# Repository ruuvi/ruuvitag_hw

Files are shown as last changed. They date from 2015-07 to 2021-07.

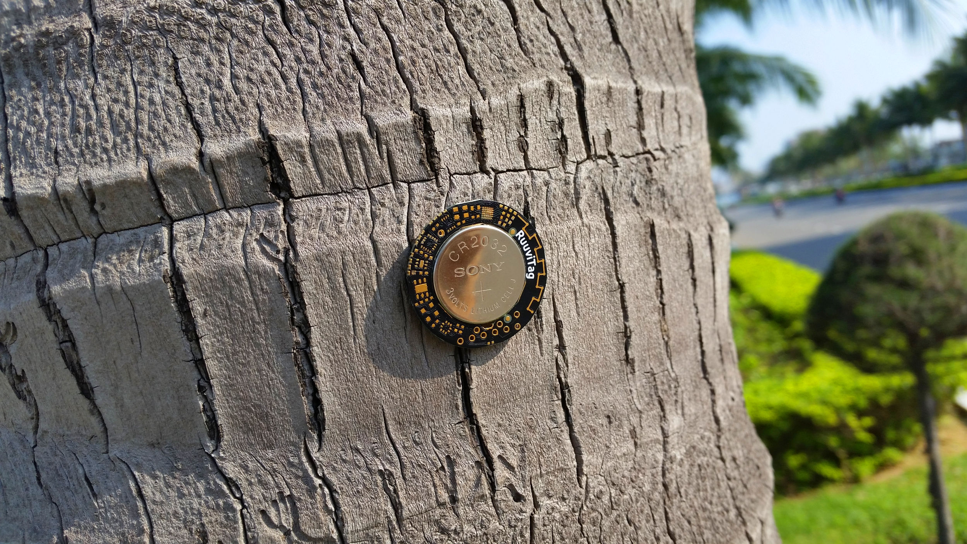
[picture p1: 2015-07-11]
ruuvitag_reva1/ruuvitag_reva1.jpg

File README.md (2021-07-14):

# RuuviTag: Open-Source Sensor Platform

* Rev.A1 - the first RuuviTag ever invented.
* Rev.A2 - minor modifications. Note: neither A1 or A2 are currently mass produced by Ruuvi.
* Rev.B1 - a completely new design. Larger footprint, nRF52 radio chip etc.
* Rev.B2 - an enhanced version of the B1.
* Rev.B3 - an enhanced version of the B2.
* Rev.B4 - an enhanced version of the B3.
* Rev.B5 - an enhanced version of the B4.
* Rev.B6 - an enhanced version of the B5.
* Rev.B7.1 - an enhanced version of the B6.
* Rev.B8 - an enhanced version of the B7.1.

All the design files are licensed using Attribution-ShareAlike 4.0 International (CC BY-SA 4.0).
Copyright: Lauri Jämsä, Ruuvi Innovations Ltd. Neither the name of the RuuviTag nor the names of its contributors may be used to endorse or promote products derived from this project without specific prior written permission. While unofficial products should not have "Ruuvi" in their name, it's okay to describe your product in relation to the Ruuvi projects. More info: license@ruuvi.com.

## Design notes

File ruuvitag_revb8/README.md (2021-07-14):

# RuuviTag Rev.B8

### Changelog after Rev.B7.1:

* Remove the reset button
* Remove the reverse polarity protection FET
* Make all the vias smaller
* Add a TMP117
* Replace the BME280 with a DPS310
* Add external I2C pull-ups
* Power sensors using GPIO pins
* 100nF caps to 1uF (except the nRF’s DEC cap)
* Add a 47uF cap
* Connect P0.26 to GND to supress radio emissions

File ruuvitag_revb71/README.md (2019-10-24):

# RuuviTag Rev.B7.1

### Changelog after Rev.B6:

* Add NFC series inductors L4 and L5
* Add a second BME280 bypass cap C15
* Modify battery clip's footprint to support also SMD parts
* Enhance button footprints
* Add two new alignment holes and a PCB edge alignment slot
* Modify battery holder's PCB shape
* Several minor layout modifications
* Add an optional SHTC3

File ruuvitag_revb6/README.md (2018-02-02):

# RuuviTag Rev.B6

### Changelog after Rev.B5:

* Replace the 10-pin 0.05" pitch ARM debug connector by TagConnect and connect its pin #1 to +BATT instead of VDD.
* Make buttons’ pads larger

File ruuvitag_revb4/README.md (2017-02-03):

# RuuviTag Rev.B4

### Changelog after Rev.B3:

* Remove SPI_MOSI and VDD traces from under BME280
* Alignment holes 1mm -> 1.2mm
* Bottom solder mask cutout under the nRF52 to avoid risk of mask pocket
* Add R and B silkscreen markings
* Two new test points: P24 and P25. Connected to P0.31 and P0.30.
* Many minor modifications to routing

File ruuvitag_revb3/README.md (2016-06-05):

# RuuviTag Rev.B3

### Changelog after Rev.B2:

#### Schema

* Accelerometer from LIS3 (3x3mm) series to LIS2 (2x2mm) series. Default component: LIS2DH12
* Add INT2 line (accelerometer). Connected to P0.06

#### Layout

* Make battery holder mechanism stronger (1mm -> 1.2mm) and tighter (~50um)
* Move P10 test point to new location
* Move P11 test point to 0.5mm lower position
* New buttons

#### Accelerometer otions (TBD)

* LIS2DH12: 12bit, 2-16g, 1Hz-5.3kHz, 32 level FIFO, 1000pcs 0.638EUR (Mouser)
* LIS2DE12: 8bit, 2-16g, 1Hz-5.3kHz, 32 level FIFO, 0.616EUR (Mouser)
* IIS2DH: 12bit, 2-16g, 1Hz-5.3kHz, 32 level FIFO, 1000pcs 1.45EUR (Mouser)
* MIS2DH: 2.16g, 1Hz-5.3kHz, no FIFO

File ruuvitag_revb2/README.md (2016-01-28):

# RuuviTag Rev.B2

Changelog after Rev.B1:

* Remove useless pull-up resistor from BUTTON1 (nRF52 has internal ones)
* Name LED3 to LED2
* Mark C12 (connected to DEC2 pin) to not assembled
* Remove SPI DataFlash
* Remove 0ohm series resistor from antenna output
* Remove PI antenna matching network (leave the shunt)
* 32MHz crystal from 3225 to 2016 size
* Completely redesigned battery holder mechanism
* LEDs from 0402 to 0603 (more low forward voltage choices available in 0603 size)
* Add a NFC antenna 
* Fix accelerometer's footprint (LGA-16) according STM's TN0018 application note. ADXL363 not supported any more (but probably reflows correctly anyways)
* SPI_ACC_CS from P0.11 to P0.08
* Remove test pads from P0.26 and P0.27
* Add test pads to P0.04, P0.05, P0.13, P0.17, P0.19, P0.25, P0.28, P0.29, GND, GND, VDD, Bat+, SWO, SWDIO, SWDCLK and RESET
* Update BOM's critical components according Nordic's reference design

Accelerometer options:

* H3LIS100DL: 8bit, 100g, 400Hz
* H3LIS200DL: 8bit, 100-200g, 1kHz
* H3LIS331DL: 12bit, 100-400g, 1kHz
* LIS331DLH: 2-8g, 1uA sleep, 10uA 10Hz, 250uA 1kHz max datarate, 1000pcs 1EUR (Mouser)
* LIS331HH: 12bit, 6-24g, 1uA sleep, 10uA 10Hz, 250uA 1kHz max datarate, 1000pcs 2.4EUR (Mouser)
* LIS3DSH: 16bit, 2-16g, 2uA sleep, 11uA 3Hz, 225uA 1.6kHz max datarate, 1000pcs 1.3EUR (Mouser)
* LIS3DH: 16bit, 2-16g, 0.5uA sleep, 2uA 1Hz, 11uA 50Hz, 5kHz max datarate, 1000pcs 0.96EUR (Mouser)
* LIS3DE: 8bit, 2-16g, 0.5uA sleep, 2uA 1Hz, 11uA 50Hz, 5kHz max datarate, 1000pcs 0.6EUR (Mouser, not yet in stock)

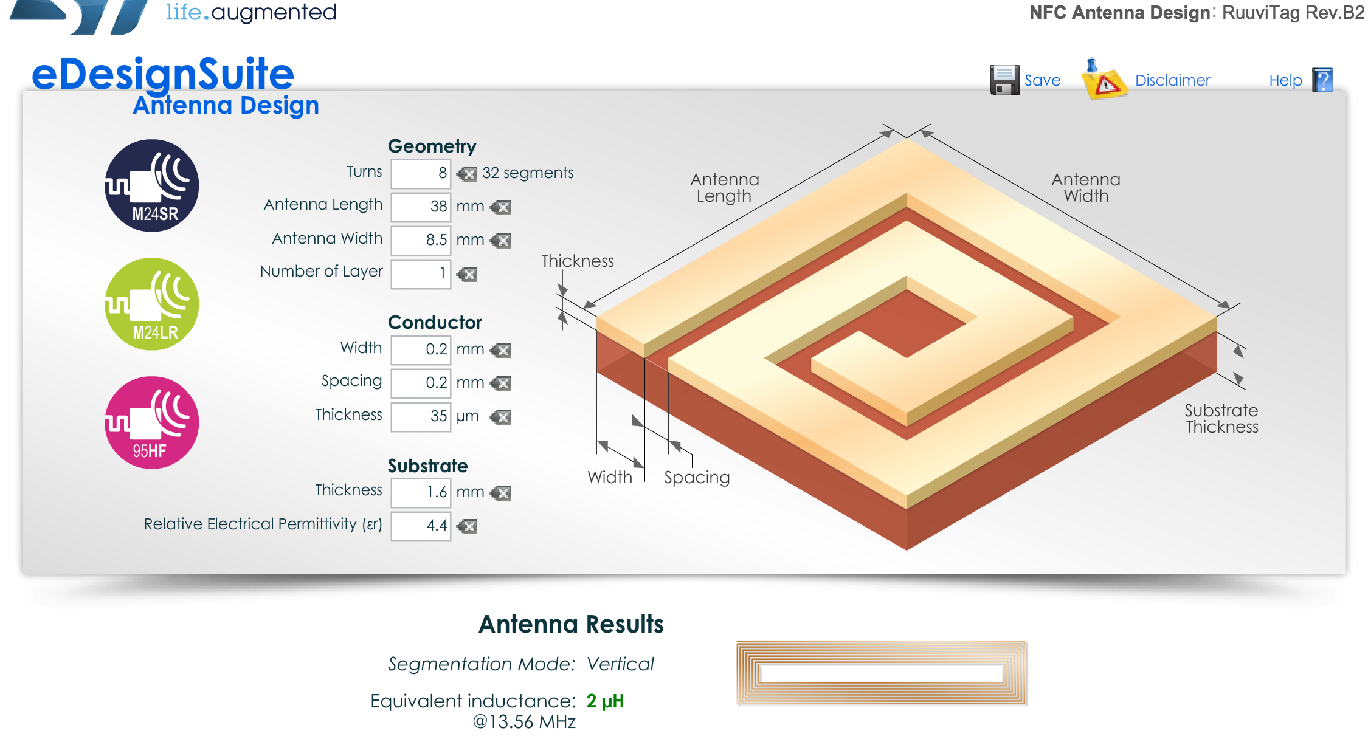
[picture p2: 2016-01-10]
ruuvitag_revb2/nfc-antenna/antenna-specs.png

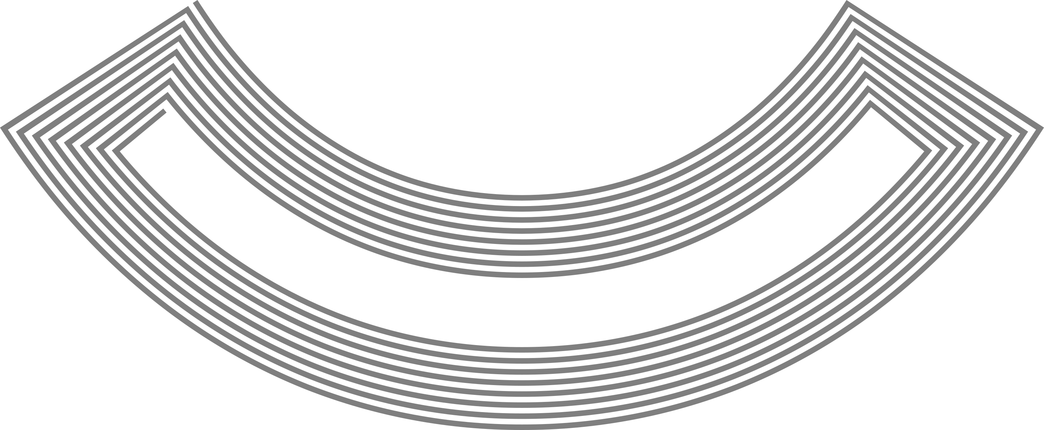
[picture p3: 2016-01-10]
ruuvitag_revb2/nfc-antenna/inkscape_export_2000dpi.png

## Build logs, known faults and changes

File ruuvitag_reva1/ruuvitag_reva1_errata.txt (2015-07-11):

Known HW limitations:

1) 16MHz crystal pinout is wrooong.

FIX: Turn crystal oscillator 90 degrees to left (or right).

2) Mysterious behaviour of reset pin. Not proven to happen too often, probably not an issue. DA14580 should have an internal pull-down resistor.

FIX: Nope.

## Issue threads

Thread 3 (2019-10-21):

Tagconnect orientation differs between revb6 files and actual PCB

PetteriAimonen, 2019-10-21:
First of all, thanks for the great product! I'll just point out this minor difference that I noticed.

The revb6 files from this repository look like this, with a single tagconnect hole towards the edge:
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

But the PCB looks like this, with two tagconnect holes towards the edge:
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

The reason I noticed this is because I designed a small add-on pcb that solders onto the testpads:
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

laurijamsa, 2019-10-24:
Orientation of the connector has changed after B6. See the latest B7.1 project design files for more info.

Closed 2019-10-24.

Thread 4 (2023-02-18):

KiCad v7/v6 "rescue symbols" error opening schematic (b8)

SensorPlay, 2023-02-18:
Opening the project file > schematic generates "rescue symbols" error (screencap)

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

I thought this may be a new version error, so I rolled back to 5.1.8 KiCad (the version on the schematic pdf), but same errors are generated.

I'm not a super experienced KiCad user (Altium), but usually with library errors there's a library file that needs to be imported?

Cool project btw.

laurijamsa, 2023-02-19:
These aren't actually errors but the app just notifies you that some old symbols may break the schematic when opened. I just tried to open the same project using KiCad 7 and it opened just fine. Download this schematic component library and place it in same folder with the ruuvitag_hw folder and then relative library paths of the project should work correctly: https://github.com/ruuvi/kicad-library

Closed 2023-02-19.

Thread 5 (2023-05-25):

What kind/model of antenna do you use to achieve long range?

Michaelszeng, 2023-05-25:
The schematics don't seem to specify.

laurijamsa, 2023-05-26:
It is a custom PCB antenna. You can open the electronics project using KiCad.

Closed 2023-05-26.

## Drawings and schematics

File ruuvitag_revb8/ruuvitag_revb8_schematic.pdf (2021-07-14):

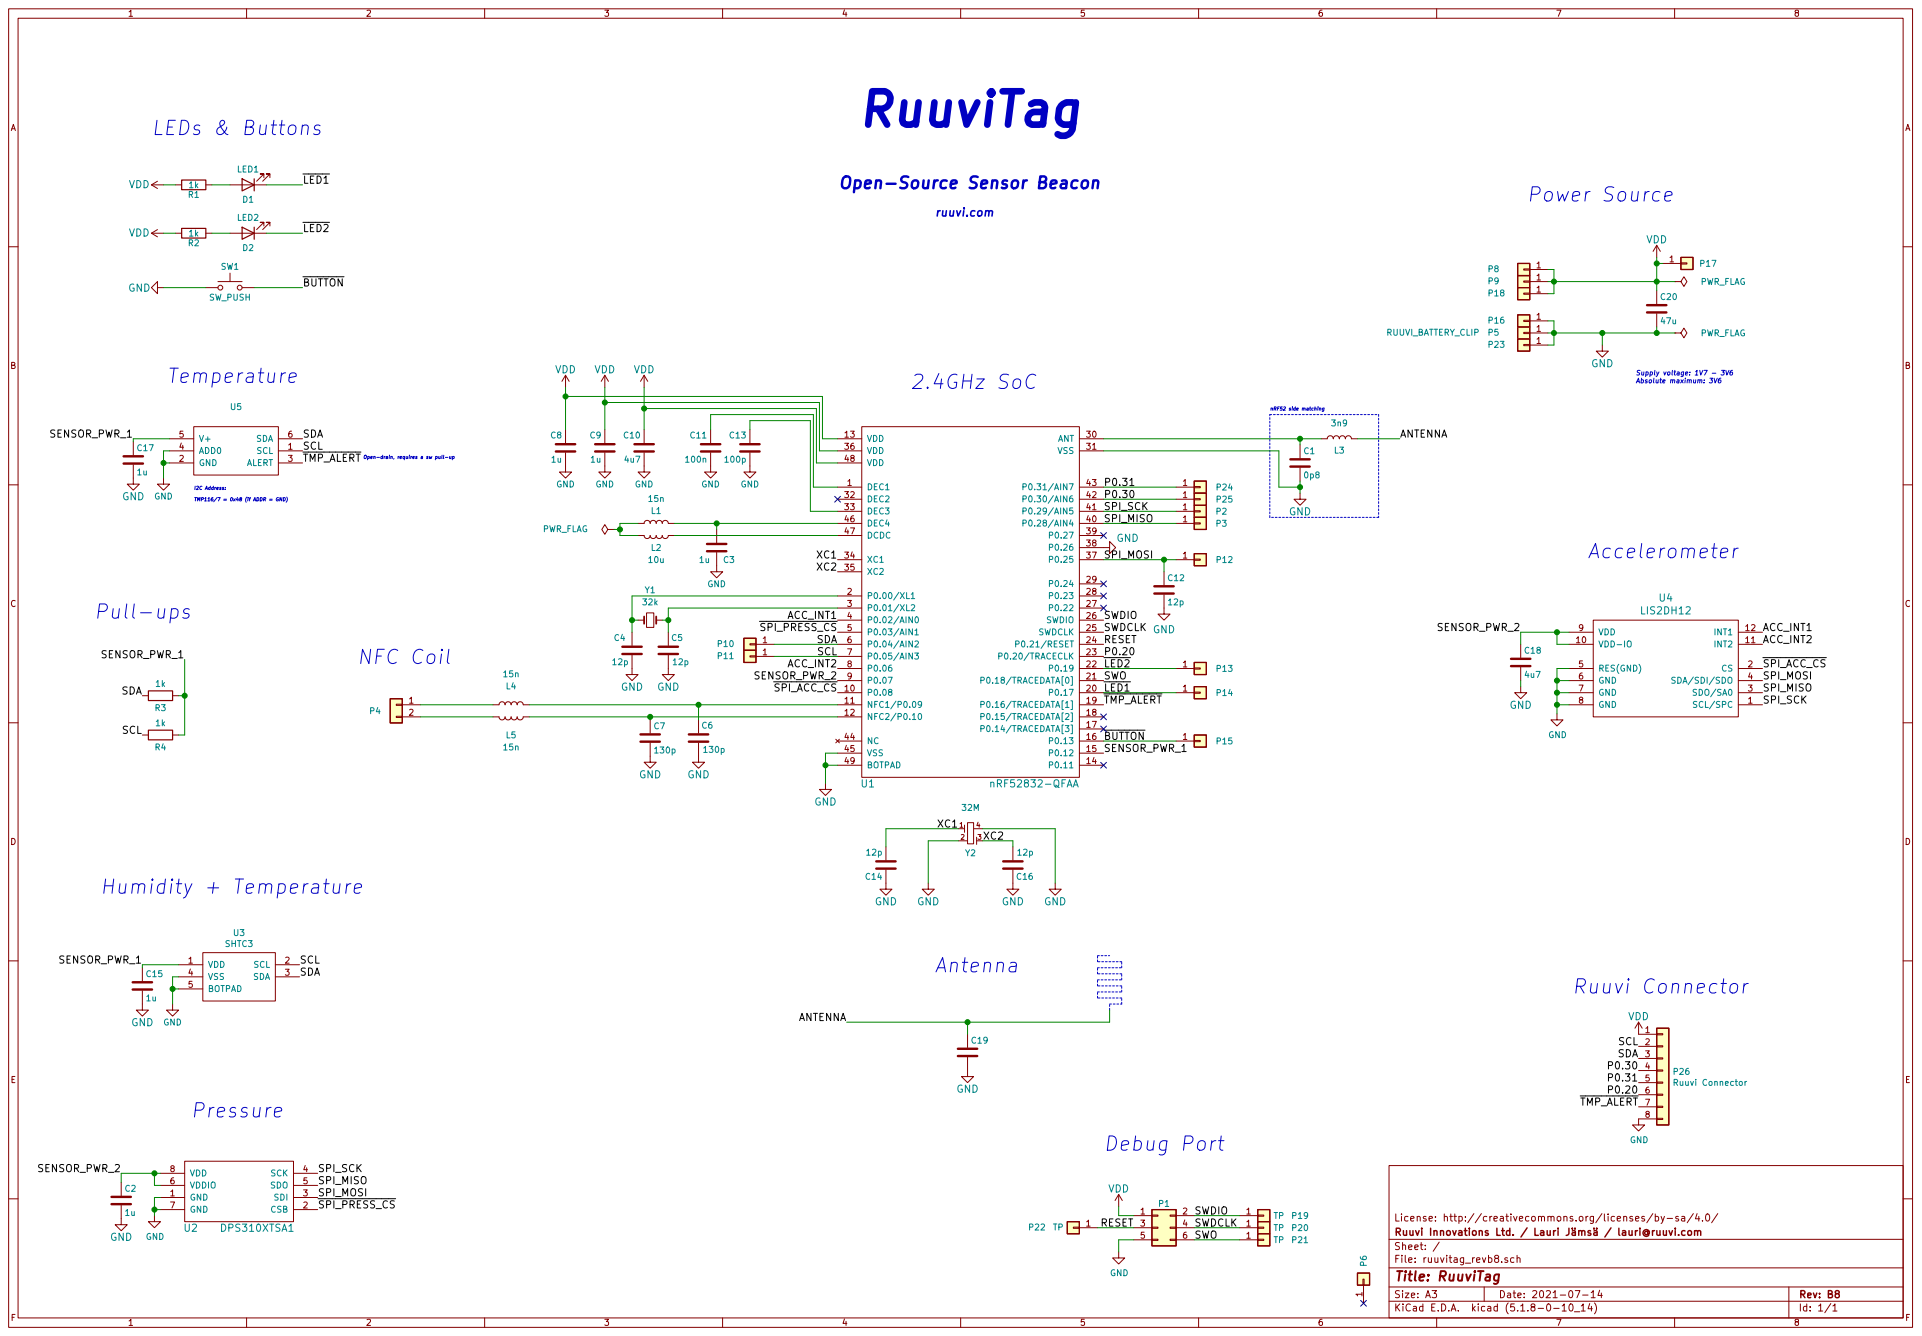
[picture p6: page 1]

nRF52 side matching Open-drain, requires a sw pull-up LEDs & Buttons

Open-Source Sensor Beacon

Supply voltage: 1V7 - 3V6 Absolute maximum: 3V6 Pull-ups

SPI_PRESS_CS

SCL

License: http://creativecommons.org/licenses/by-sa/4.0/
File: ruuvitag_revb8.sch Sheet: / Ruuvi Innovations Ltd. / Lauri Jämsä / lauri@ruuvi.com

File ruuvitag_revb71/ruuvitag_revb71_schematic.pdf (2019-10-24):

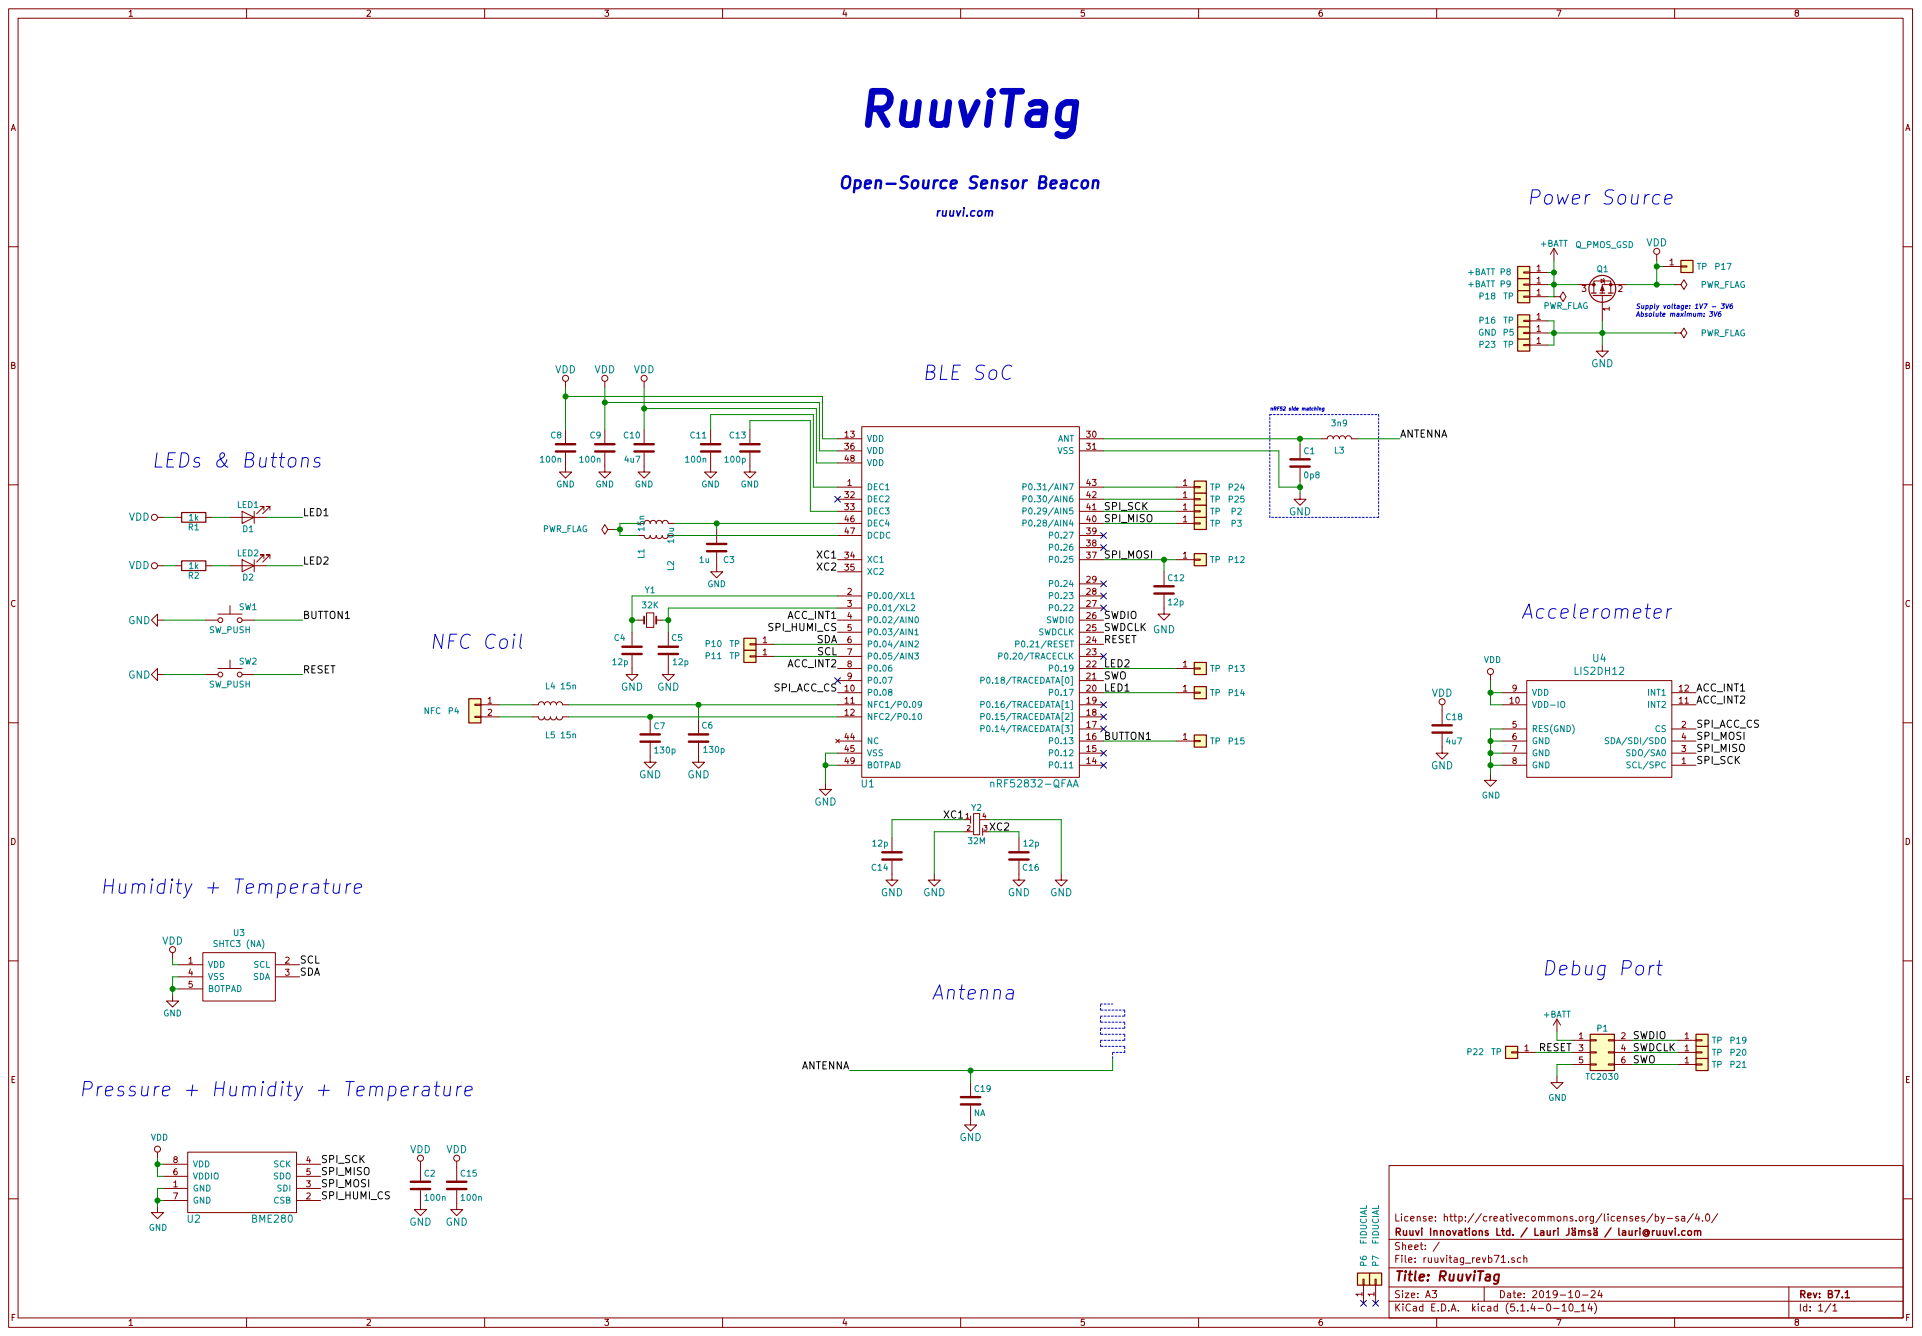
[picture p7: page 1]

Power Source Open-Source Sensor Beacon

Supply voltage: 1V7 - 3V6 Absolute maximum: 3V6 Pressure + Humidity + Temperature

nRF52 side matching NFC Coil

SPI_HUMI_CS | ACC_INT1

SCL

1 P7 FIDUCIAL
License: http://creativecommons.org/licenses/by-sa/4.0/
File: ruuvitag_revb71.sch Sheet: / Ruuvi Innovations Ltd. / Lauri Jämsä / lauri@ruuvi.com

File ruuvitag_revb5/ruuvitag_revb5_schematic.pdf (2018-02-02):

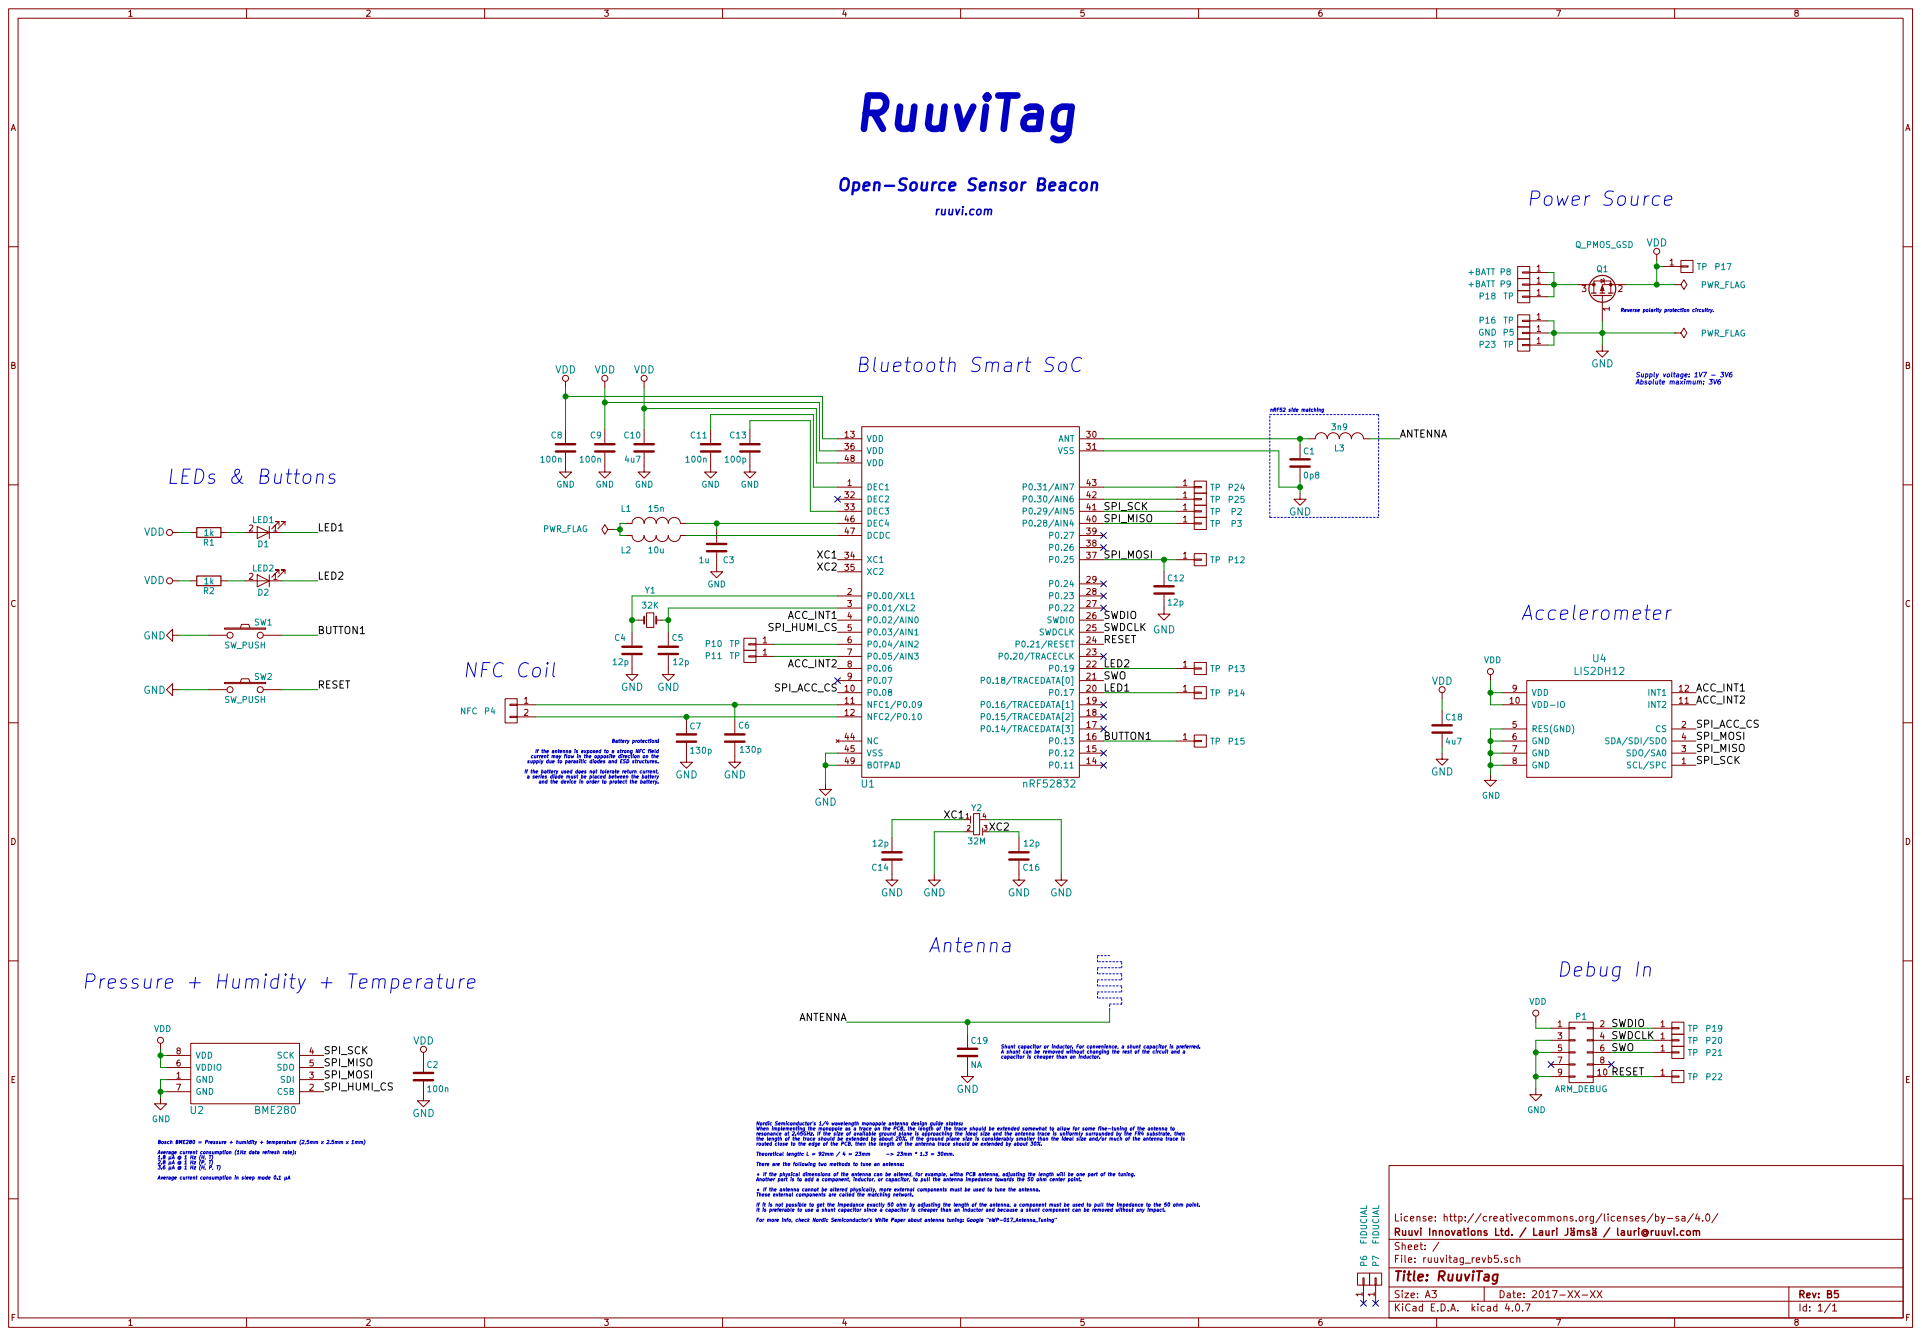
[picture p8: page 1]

Open-Source Sensor Beacon

Supply voltage: 1V7 - 3V6 Absolute maximum: 3V6 1 +BATT P8 LED2

Reverse polarity protection circuitry.

If the antenna is exposed to a strong NFC field
current may flow in the opposite direction on the
supply due to parasitic diodes and ESD structures.

Shunt capacitor or inductor. For convenience, a shunt capacitor is preferred. A shunt can be removed without changing the rest of the circuit and a
capacitor is cheaper than an inductor.

Nordic Semiconductor's 1/4 wavelength monopole antenna design guide states: When implementing the monopole as a trace on the PCB, the length of the trace should be extended somewhat to allow for some fine-tuning of the antenna to
resonance at 2.45GHz. If the size of available ground plane is approaching the ideal size and the antenna trace is uniformly surrounded by the FR4 substrate, then
the length of the trace should be extended by about 20%. If the ground plane size is considerably smaller than the ideal size and/or much of the antenna trace is

If the physical dimensions of the antenna can be altered, for example, witha PCB antenna, adjusting the length will be one part of the tuning. Another part is to add a component, inductor, or capacitor, to pull the antenna impedance towards the 50 ohm center point.

If the antenna cannot be altered physically, more external components must be used to tune the antenna. These external components are called the matching network.

If it is not possible to get the impedance exactly 50 ohm by adjusting the length of the antenna, a component must be used to pull the impedance to the 50 ohm point.

1 P7 FIDUCIAL
License: http://creativecommons.org/licenses/by-sa/4.0/
File: ruuvitag_revb5.sch Sheet: / Ruuvi Innovations Ltd. / Lauri Jämsä / lauri@ruuvi.com

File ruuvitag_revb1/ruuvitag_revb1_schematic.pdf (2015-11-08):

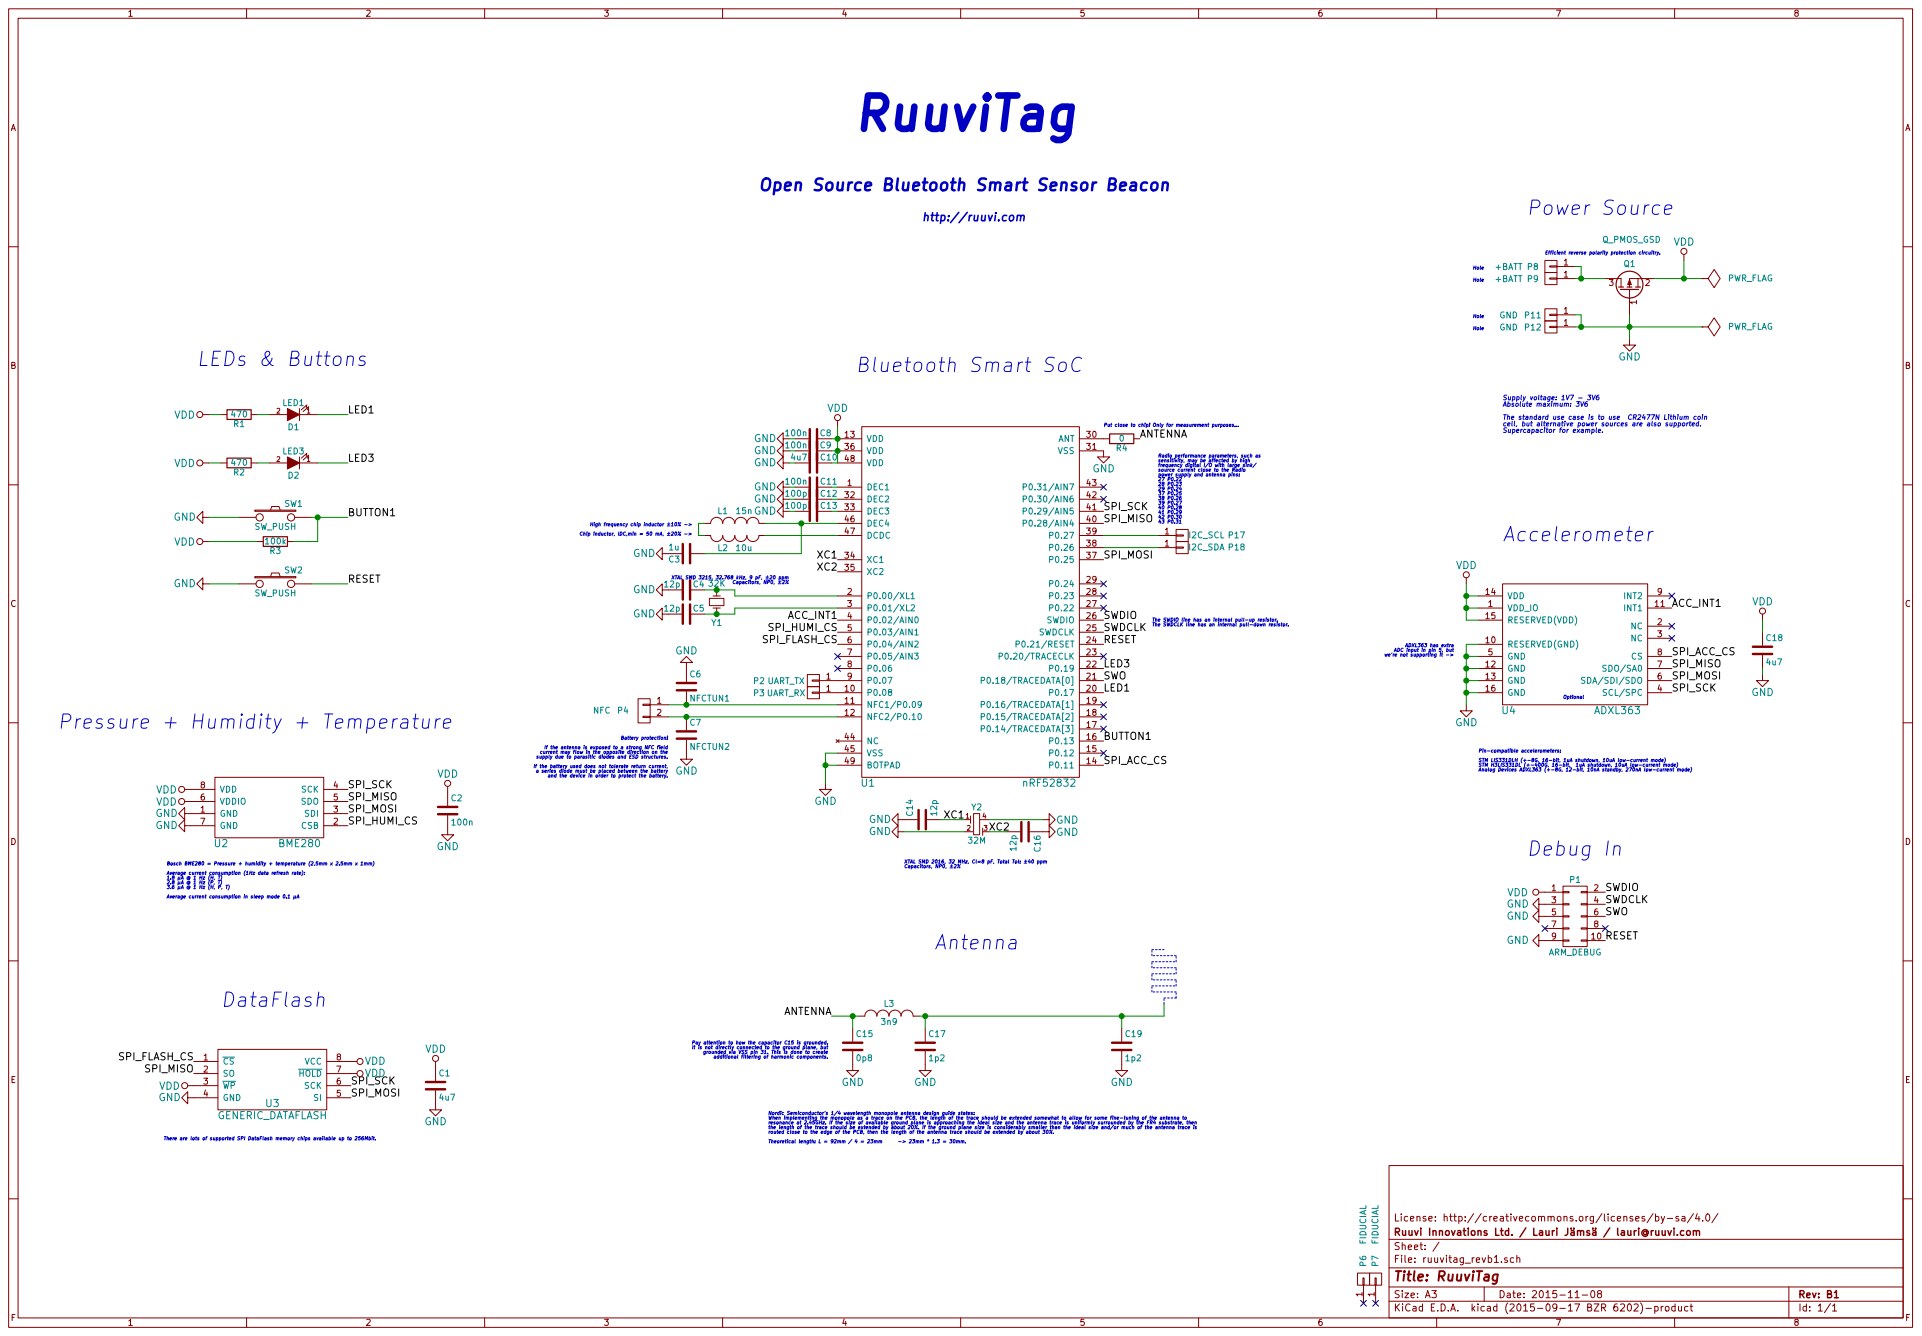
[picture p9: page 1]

Open Source Bluetooth Smart Sensor Beacon

cell, but alternative power sources are also supported. Supercapacitor for example. 1 +BATT P8
1 +BATT P9

Hole Hole Hole Hole R4

Supply voltage: 1V7 - 3V6 Absolute maximum: 3V6 The standard use case is to use CR2477N Lithium coin

Put close to chip! Only for measurement purposes... High frequency chip inductor ±10% -> Chip inductor, IDC,min = 50 mA, ±20% ->

XTAL SMD 3215, 32.768 kHz, 9 pF, ±20 ppm

Pin-compatible accelerometers: STM LIS331DLH (+-8G, 16-bit, 1uA shutdown, 10uA low-current mode) STM H3LIS331DL (+-400G, 16-bit, 1uA shutdown, 10uA low-current mode) Analog Devices ADXL363 (+-8G, 12-bit, 10nA standby, 270nA low-current mode) ACC_INT1
SPI_HUMI_CS
SPI_FLASH_CS

ADXL363 has extra ADC input in pin 5, but we're not supporting it -> 1

If the antenna is exposed to a strong NFC field
current may flow in the opposite direction on the
supply due to parasitic diodes and ESD structures.
If the battery used does not tolerate return current, a series diode must be placed between the battery and the device in order to protect the battery.

XTAL SMD 2016, 32 MHz, Cl=8 pF, Total Tol: ±40 ppm
Capacitors, NP0, ±2%

Pay attention to how the capacitor C15 is grounded.
It is not directly connected to the ground plane, but grounded via VSS pin 31. This is done to create
additional filtering of harmonic components.

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

There are lots of supported SPI DataFlash memory chips available up to 256Mbit.

1 P7 FIDUCIAL
License: http://creativecommons.org/licenses/by-sa/4.0/
File: ruuvitag_revb1.sch Sheet: / Ruuvi Innovations Ltd. / Lauri Jämsä / lauri@ruuvi.com

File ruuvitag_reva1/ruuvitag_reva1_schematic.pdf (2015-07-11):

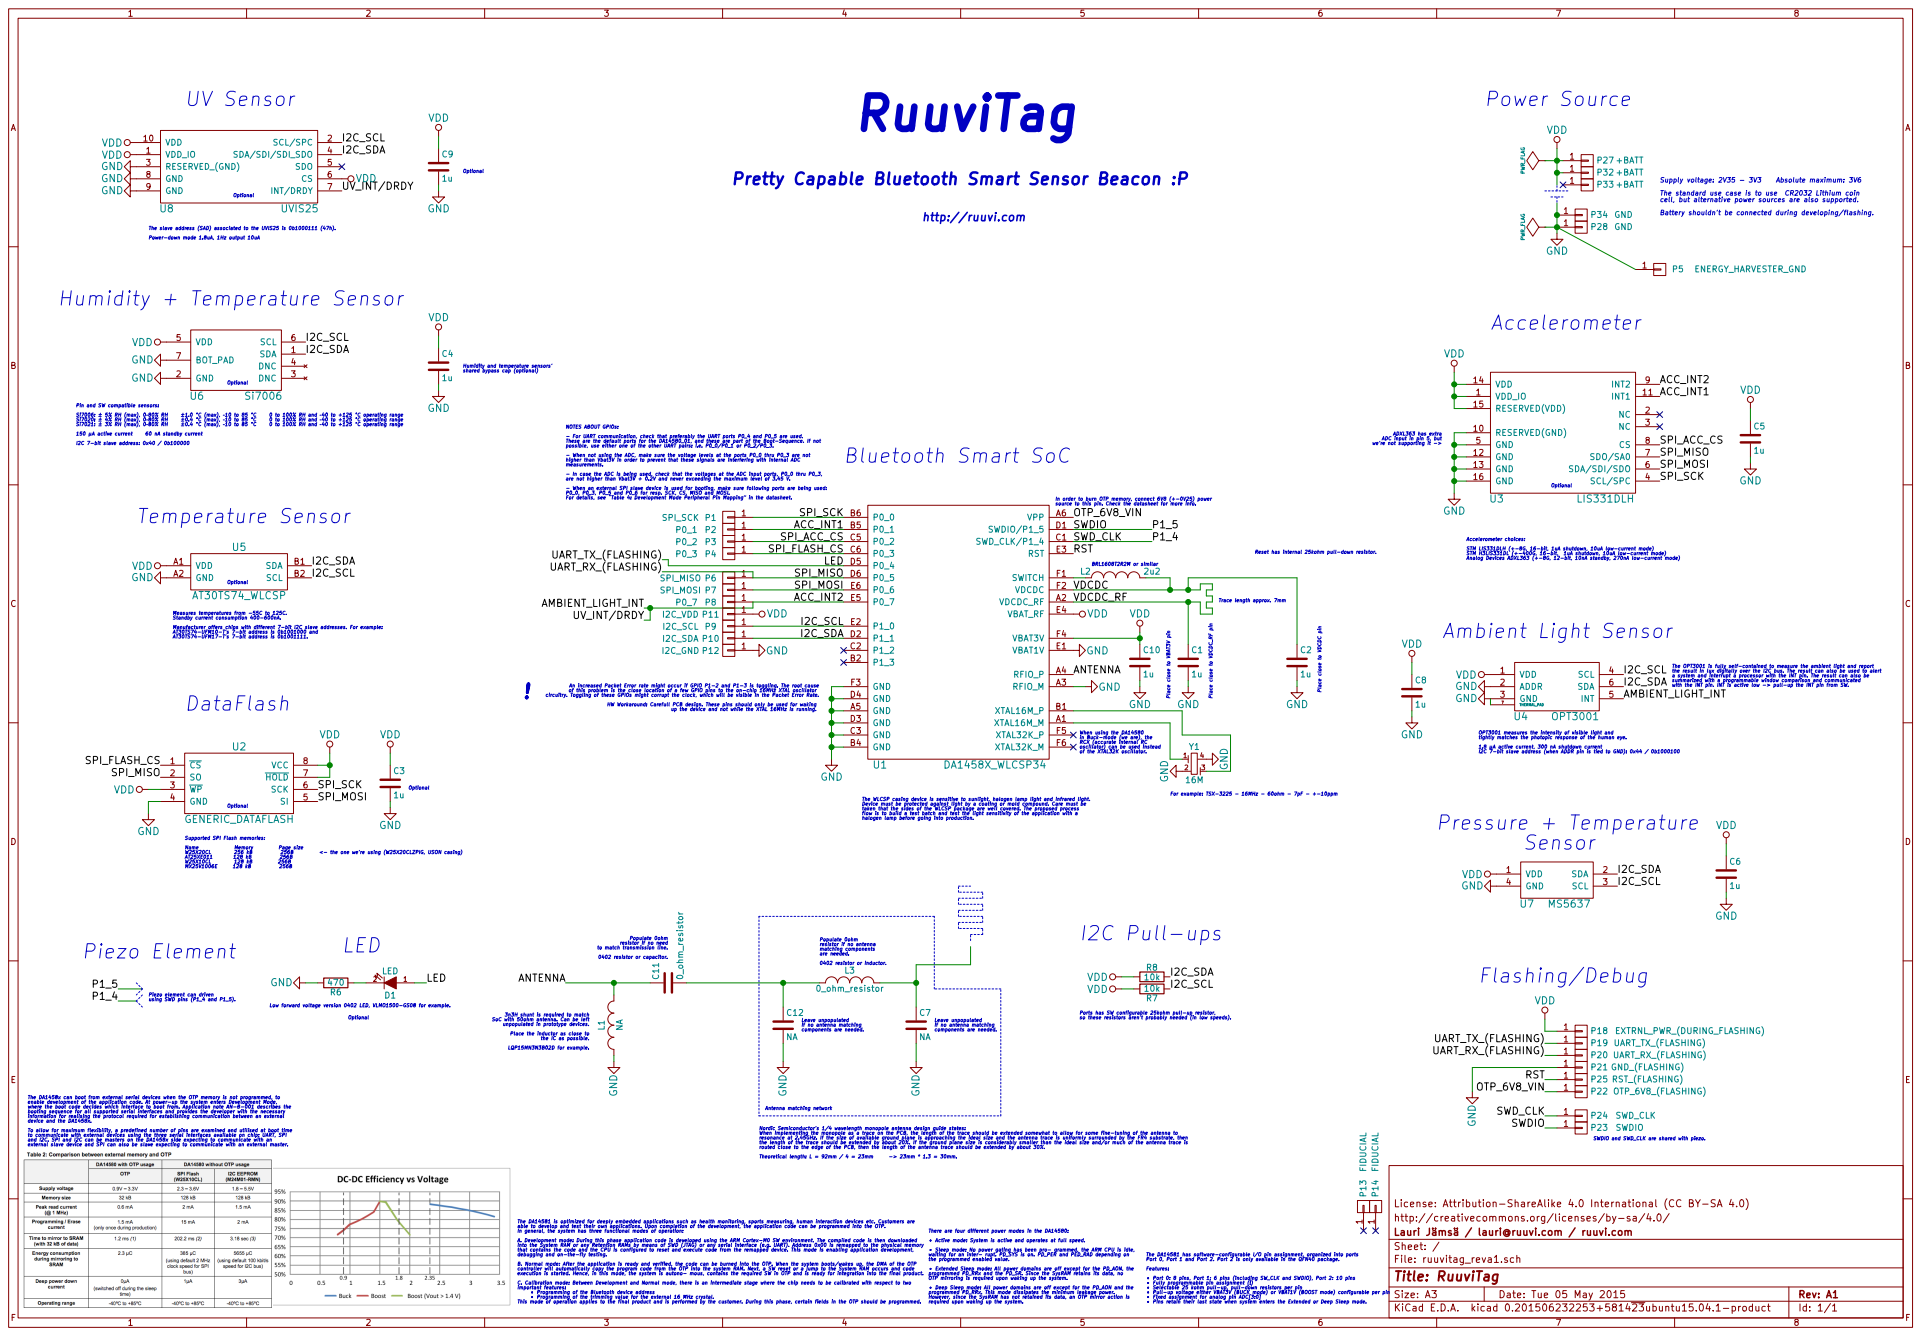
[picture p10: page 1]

Pretty Capable Bluetooth Smart Sensor Beacon :P

Supply voltage: 2V35 - 3V3 Absolute maximum: 3V6 The standard use case is to use CR2032 Lithium coin

Humidity and temperature sensors' shared bypass cap (optional)

Pin and SW compatible sensors: Si7006: ± 5% RH (max), 080% RH ±1.0 °C (max), 10 to 85 °C 0 to 100% RH and 40 to +125 °C operating range Si7020: ± 4% RH (max), 080% RH ±0.4 °C (max), 10 to 85 °C 0 to 100% RH and 40 to +125 °C operating range Si7021: ± 3% RH (max), 080% RH ±0.4 °C (max), 10 to 85 °C 0 to 100% RH and 40 to +125 °C operating range

150 µA active current 60 nA standby current

Bluetooth Smart SoC
in Buck-mode (we are), the RCX (accurate internal RC oscillator) can be used instead of the XTAL32K oscillator. BRL1608T2R2M or similarC10
VDCDC
VDCDC_RF

In order to burn OTP memory, connect 6V8 (+-0V25) power source to this pin. Check the datasheet for more info.
OTP_6V8_VIN
SWDIO
SWD_CLK
RST

SPI_SCK
ACC_INT1
SPI_ACC_CS
Accelerometer choices: STM LIS331DLH (+-8G, 16-bit, 1uA shutdown, 10uA low-current mode) STM H3LIS331DL (+-400G, 16-bit, 1uA shutdown, 10uA low-current mode) Analog Devices ADXL363 (+-8G, 12-bit, 10nA standby, 270nA low-current mode) ACC_INT2
SPI_FLASH_CS

Reset has internal 25kohm pull-down resistor.

Ambient Light Sensor VDD GND

1u GND Place close to VDCDC pin

of this problem is the close location of a few GPIO pins to the on-chip 16MHz XTAL oscillator circuitry. Toggling of these GPIOs might corrupt the clock, which will be visible in the Packet Error Rate. HW Workaround: Carefull PCB design. These pins should only be used for waking up the device and not while the XTAL 16MHz is running. !

the result in lux digitally over the I2C bus. The result can also be used to alert a system and interrupt a processor with the INT pin. The result can also be
summarized with a programmable window comparison and communicated with the INT pin. INT is active low -> pull-up the INT pin from SW.

An increased Packet Error rate might occur if GPIO P1-2 and P1-3 is toggling. The root cause

For example: TSX-3225 - 16MHz - 60ohm - 7pF - +-10ppm When using the DA14580

OPT3001 measures the intensity of visible light and
tightly matches the photopic response of the human eye. 1.8 µA active current, 300 nA shutdown current

The WLCSP casing device is sensitive to sunlight, halogen lamp light and infrared light. Device must be protected against light by a coating or mold compound. Care must be
taken that the sides of the WLCSP package are well covered. The proposed process
flow is to build a test batch and test the light sensitivity of the application with a

halogen lamp before going into production. The DA1458x can boot from external serial devices when the OTP memory is not programmed, to

resistor if no need

0_ohm_resistor Populate 0ohm
resistor if no antenna matching components are needed. 0402 resistor or inductor.

SWDIO and SWD_CLK are shared with piezo. P1_5

Low forward voltage version 0402 LED, VLMO1500-GS08 for example. Piezo element can driven
using SWD pins (P1_4 and P1_5).

Ports has SW configurable 25kohm pull-up resistor, so these resistors aren't probably needed (in low speeds).

Leave unpopulated
if no antenna matching

enable development of the application code. At power-up the system enters Development Mode, where the boot code decides which interface to boot from. Application note AN-B-001 describes the
booting sequence for all supported serial interfaces and provides the developer with the necessary
information for realising the protocol required for establishing communication between an external device and the DA1458x. To allow for maximum flexibility, a predefined number of pins are examined and utilised at boot time

to communicate with external devices using the three serial interfaces available on chip: UART, SPI and I2C. SPI and I2C can be masters on the DA1458x side expecting to communicate with an
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

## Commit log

2015-07-11 Initial commit
    First commit, added Rev.A1 and Rev.A2.
    [3CR2032.fcstd, 3x3x1_grey_50trans.FCStd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]
2015-11-08 RuuviTag Rev.B1 initial commit
    [ruuvitag_revb1-B_Cu.gbl, ruuvitag_revb1-B_Mask.gbs, ruuvitag_revb1-B_SilkS.gbo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]
2016-01-09 B2 initial commit
    [ruuvitag_revb2.kicad_pcb, ruuvitag_revb2.sch]
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2016-01-09 Minor mods
    [ruuvitag_revb2.kicad_pcb]
2016-01-09 Update footprints
    [ruuvitag_revb2.kicad_pcb]
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2016-01-10 Add NFC antenna
    [ruuvitag_revb2.kicad_pcb]
2016-01-11 LEDs to 0603
    [ruuvitag_revb2.kicad_pcb]
2016-01-11 Update SOT-23
    [ruuvitag_revb2.kicad_pcb, ruuvitag_revb2.sch]
2016-01-11 Update components
    [ruuvitag_revb2.kicad_pcb]
2016-01-11 Pads to NFC antenna
    [ruuvitag_revb2.sch]
2016-01-11 NFC traces done
    [ruuvitag_revb2.kicad_pcb]
2016-01-11 Bluetooth antenna done
    [ruuvitag_revb2.kicad_pcb]
2016-01-12 Make look nicer
    [ruuvitag_revb2.sch]
2016-01-12 New accelerometer
    [ruuvitag_revb2.sch]
2016-01-12 Enhance LGA-16 footprint according TN0018 appnote
    [ruuvitag_revb2.kicad_pcb]
2016-01-12 Enhance BME280 footprint according the data sheet
    [ruuvitag_revb2.kicad_pcb]
2016-01-12 Outline from silk to Crt
    [ruuvitag_revb2.kicad_pcb]
2016-01-12 Small mods
    [ruuvitag_revb2.kicad_pcb, ruuvitag_revb2.sch]
2016-01-12 Add nRF52 side matching components
    [ruuvitag_revb2.kicad_pcb, ruuvitag_revb2.sch]
2016-01-13 Antenna mods etc.
    [ruuvitag_revb2.kicad_pcb]
2016-01-13 Just make it look nicer
    [ruuvitag_revb2.sch]
2016-01-13 LED3 to LED2 (value only)
    [ruuvitag_revb2.sch]
2016-01-13 Arranging antenna matching components
    [ruuvitag_revb2.kicad_pcb]
2016-01-13 More traces done
    [ruuvitag_revb2.kicad_pcb]
2016-01-13 SPI_ACC_CS from P0.11 to P0.06
    [ruuvitag_revb2.kicad_pcb, ruuvitag_revb2.sch]
2016-01-13 Remove test pads from P0.26 and P0.27
    [ruuvitag_revb2.kicad_pcb, ruuvitag_revb2.sch]
2016-01-13 New test points
    [ruuvitag_revb2.sch]
2016-01-13 More traces
    [ruuvitag_revb2.kicad_pcb]
2016-01-13 Less rigid battery holder mechanism
    [ruuvitag_revb2.kicad_pcb]
2016-01-13 Change test point footprints
    [ruuvitag_revb2.sch]
2016-01-13 SPI_ACC_CS from P0.06 to P0.07
    [ruuvitag_revb2.kicad_pcb, ruuvitag_revb2.sch]
2016-01-13 More vias to nRF52 bot pad
    [ruuvitag_revb2.kicad_pcb]
2016-01-13 Update components according Nordic's ref design notes
    Infocenter: Table 3. Bill of material for QFAA QFN48 with DC/DC
    converter and NFC setup.
    [ruuvitag_revb2_bom.csv]
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2016-01-13 Change nRF52's footprint
    [ruuvitag_revb2.kicad_pcb]
2016-01-13 Add 3D models
    [ruuvitag_revb2.kicad_pcb, ruuvitag_revb2.sch]
2016-01-14 Test pin mods
    [ruuvitag_revb2.sch]
2016-01-14 More tracks
    [ruuvitag_revb2.kicad_pcb]
2016-01-14 DRC passed!
    [ruuvitag_revb2.kicad_pcb]
2016-01-14 Small fixes
    [ruuvitag_revb2.kicad_pcb]
2016-01-14 Clear crystal's manual solder mask value
    [ruuvitag_revb2.kicad_pcb]
2016-01-14 Better GND zone
    [ruuvitag_revb2.kicad_pcb]
2016-01-14 Fix 32MHz crystal (no vias on pads any more)
    [ruuvitag_revb2.kicad_pcb]
2016-01-14 Small placement fixes on antenna matching components
    [ruuvitag_revb2.kicad_pcb]
2016-01-14 More test points
    [ruuvitag_revb2.kicad_pcb, ruuvitag_revb2.sch]
2016-01-14 One more test pad
    [ruuvitag_revb2.kicad_pcb, ruuvitag_revb2.sch]
2016-01-14 Add B2 text
    [ruuvitag_revb2.kicad_pcb]
2016-01-14 Remove zone fill around antenna matching components
    [ruuvitag_revb2.kicad_pcb]
2016-01-14 Add GND plane under antenna matching components on bottom layer
    [ruuvitag_revb2.kicad_pcb]
2016-01-14 Make bottom GND plane a bit larger under the matching components
    [ruuvitag_revb2.kicad_pcb]
2016-01-15 Fix footprint
2016-01-15 Plot gerbers
    [ruuvitag_revb2-B.Cu.gbl, ruuvitag_revb2-B.Mask.gbs, ruuvitag_revb2-B.SilkS.gbo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]
2016-01-15 Update nRF52 footprint
    [ruuvitag_revb2.kicad_pcb]
2016-01-15 Make it look nicer
    [ruuvitag_revb2.sch]
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2016-01-15 Add 3pcs of 1mm non-plated holes
    [ruuvitag_revb2.kicad_pcb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]
2016-01-15 More test pads
    [ruuvitag_revb2-B.Cu.gbl, ruuvitag_revb2-B.Mask.gbs, ruuvitag_revb2-B.Paste.gbp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]
2016-01-15 Minor mod
    [ruuvitag_revb2.kicad_pcb]
2016-01-15 Move test pads to better locations
    [ruuvitag_revb2-B.Cu.gbl, ruuvitag_revb2-B.Mask.gbs, ruuvitag_revb2-B.Paste.gbp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]
2016-01-15 Move test pins a bit
    [ruuvitag_revb2-B.Cu.gbl, ruuvitag_revb2-B.Mask.gbs, ruuvitag_revb2-B.Paste.gbp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]
2016-01-15 Second GND test pad
    [ruuvitag_revb2-B.Cu.gbl, ruuvitag_revb2-B.Mask.gbs, ruuvitag_revb2-B.Paste.gbp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]
2016-02-05 Update LED 3D model path
    [ruuvitag_revb2.kicad_pcb]
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2016-02-05 Add 3D model of CR2450
    [ruuvitag_revb2.kicad_pcb]
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2016-02-05 KiCad StepUp script for B2
    [ksu-config.cfg]
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2016-02-06 Add battery contact 3d model
    [ruuvitag_revb2.kicad_pcb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]
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2018-02-02 Add Rev.B5 HW design files
    [ruuvitag_revb5.kicad_pcb, ruuvitag_revb5.sch]
2018-02-02 Add Rev.B6 HW design files
    [ruuvitag_revb6.kicad_pcb, ruuvitag_revb6.sch]
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2019-06-28 Remove several obsolete files and reorganise folders
    [3CR2032.fcstd, 3x3x1_grey_50trans.FCStd, CR2450.fcstd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]
2019-10-24 Add B7.1 project files
    [ruuvitag_revb71.kicad_pcb, ruuvitag_revb71.sch]
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
